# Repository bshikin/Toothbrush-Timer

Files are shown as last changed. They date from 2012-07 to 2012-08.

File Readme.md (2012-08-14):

Toothbrush Timer
=================

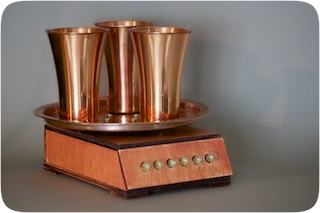
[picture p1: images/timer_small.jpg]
Toothbrush Timer


This is a repository for my toothbrush timer project. It contains schematic and enclosure design and program sources.

You can read how the timer was made in [this Instructable](http://instructables.com/id/Toothbrush-Timer)

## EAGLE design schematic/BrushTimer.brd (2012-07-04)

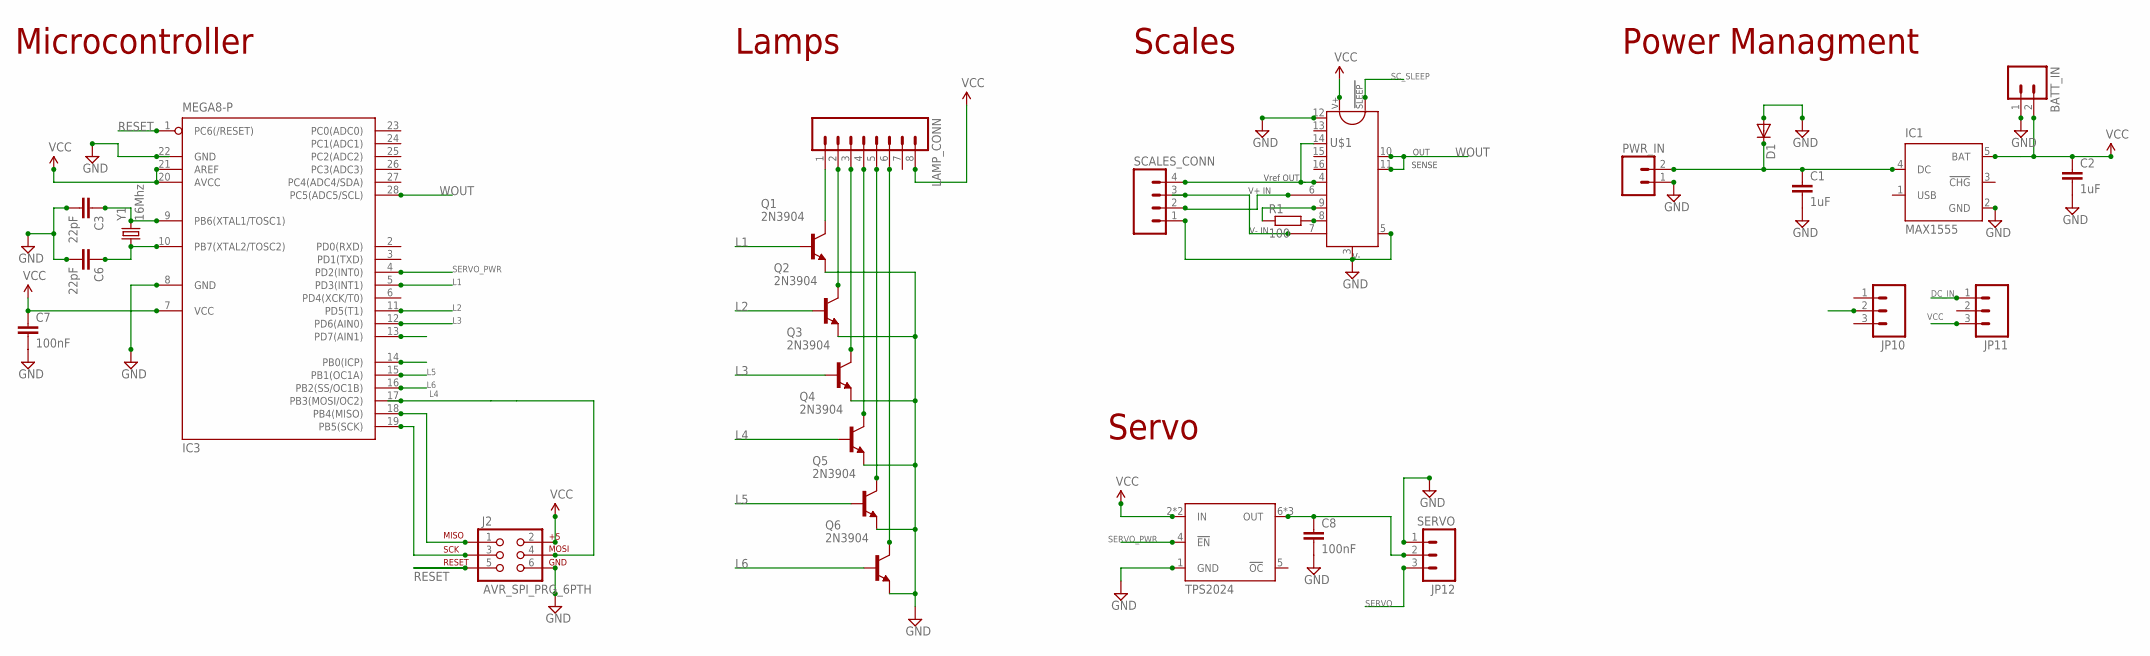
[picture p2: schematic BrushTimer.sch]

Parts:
BATT_IN: M02PTH; 1X02
C1, C2: 1uF; AXIAL-5MM
C3, C6: 22pF; C2.5-2
C7, C8: 100nF; C5B3.5
D1: DIODE-D-2.5; D-2.5
IC1: MAX1555; SOT23-5L
IC3: MEGA8-P; DIL28-3
J2: AVR_SPI_PRG_6PTH; 2X3
JP10, JP11: M03PTH; 1X03
JP12: SERVO; 1X03
LAMP_CONN: M081X08; 1X08
PWR_IN: M02PTH; 1X02
Q1, Q2, Q3, Q4, Q5, Q6: 2N3904; TO92
R1: 100; 0207/5V
SCALES_CONN: M04PTH; 1X04
U$1: INA125; DIL16
U$2: TPS2024; DIL08-OPTO
Y1: 16Mhz; HC49US

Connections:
DC_IN: C1.P$1 (1), D1.C, IC1.4 (DC), JP11.1, PWR_IN.2
GND: BATT_IN.1, C1.P$2 (2), C2.P$2 (2), C3.2, C6.2, C7.2, C8.2, D1.A, IC1.2 (GND), IC3.8 (GND), IC3.22 (GND), J2.6, JP10.2, JP12.1, PWR_IN.1, Q1.3 (E), Q2.3 (E), Q3.3 (E), Q4.3 (E), Q5.3 (E), Q6.3 (E), SCALES_CONN.1, U$1.3, U$1.5, U$1.12, U$2.1 (GND)
L1: IC3.5 (PD3(INT1)), Q1.2 (B)
L1_OUT: LAMP_CONN.1, Q1.1 (C)
L2: IC3.11 (PD5(T1)), Q2.2 (B)
L2_OUT: LAMP_CONN.2, Q2.1 (C)
L3: IC3.12 (PD6(AIN0)), Q3.2 (B)
L3_OUT: LAMP_CONN.3, Q3.1 (C)
L4: IC3.17 (PB3(MOSI/OC2)), J2.4, Q4.2 (B)
L4_OUT: LAMP_CONN.4, Q4.1 (C)
L5: IC3.15 (PB1(OC1A)), Q5.2 (B)
L5_OUT: LAMP_CONN.5, Q5.1 (C)
L6: IC3.16 (PB2(SS/OC1B)), Q6.2 (B)
L6_OUT: LAMP_CONN.6, Q6.1 (C)
MISO: IC3.18 (PB4(MISO)), J2.1
unnamed: SCALES_CONN.2, U$1.6
RESET: IC3.1 (PC6(/RESET)), J2.5
RG1: R1.1, U$1.9
RG2: R1.2, U$1.8
SCK: IC3.19 (PB5(SCK)), J2.3
SC_SLEEP: IC3.13 (PD7(AIN1)), U$1.2
SERVO: IC3.14 (PB0(ICP)), JP12.3
SERVO_PWR: IC3.4 (PD2(INT0)), U$2.4 (!EN)
SERVO_VCC: C8.1, JP12.2, U$2.6 (OUT), U$2.7 (OUT), U$2.8 (OUT)
V-IN: SCALES_CONN.3, U$1.7
VCC: BATT_IN.2, C2.P$1 (1), C7.1, IC1.5 (BAT), IC3.7 (VCC), IC3.20 (AVCC), IC3.21 (AREF), J2.2, JP11.3, LAMP_CONN.8, U$1.1, U$2.2 (IN), U$2.3 (IN)
VREF-OUT: SCALES_CONN.4, U$1.4, U$1.14
WOUT: IC3.28 (PC5(ADC5/SCL)), U$1.10, U$1.11
XTAL9: C3.1, IC3.9 (PB6(XTAL1/TOSC1)), Y1.2
XTAL19: C6.1, IC3.10 (PB7(XTAL2/TOSC2)), Y1.1

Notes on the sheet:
Microcontroller
Lamps
Scales
Power Managment
Servo

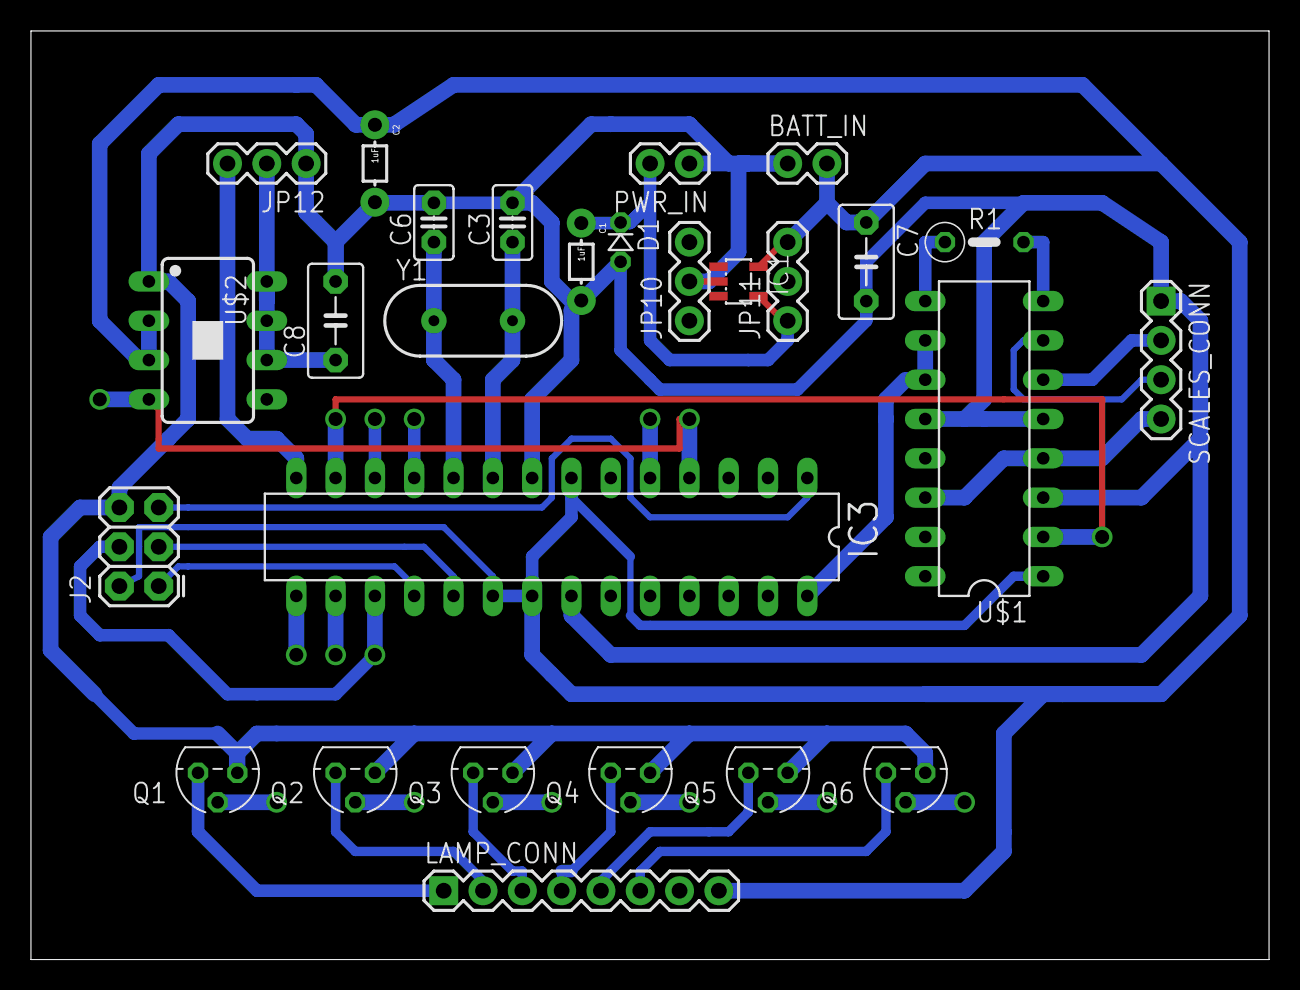
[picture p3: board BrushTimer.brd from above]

Board: 2 copper layers, 80.0 x 60.0 mm, 27 parts (0 on the bottom side), 30 nets.

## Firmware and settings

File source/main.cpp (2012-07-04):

/**
 * Copyright (c) 2012 Basil Shikin, BrushTimer Project
 *
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
 * THE SOFTWARE IS PROVIDED "AS IS", WITHOUT WARRANTY OF ANY KIND, EXPRESS OR
 * IMPLIED, INCLUDING BUT NOT LIMITED TO THE WARRANTIES OF MERCHANTABILITY,
 * FITNESS FOR A PARTICULAR PURPOSE AND NONINFRINGEMENT. IN NO EVENT SHALL THE
 * AUTHORS OR COPYRIGHT HOLDERS BE LIABLE FOR ANY CLAIM, DAMAGES OR OTHER
 * LIABILITY, WHETHER IN AN ACTION OF CONTRACT, TORT OR OTHERWISE, ARISING FROM,
 * OUT OF OR IN CONNECTION WITH THE SOFTWARE OR THE USE OR OTHER DEALINGS IN
 * THE SOFTWARE.
 */

#include "main.h"

extern "C" void __cxa_pure_virtual()
{
  cli();
  for (;;);
}

__extension__ typedef int __guard __attribute__((mode (__DI__)));

void * operator new[](size_t size)
{
    return malloc(size);
}

void operator delete[](void * ptr)
{
    if (ptr)
        free(ptr);
}

int __cxa_guard_acquire(__guard *g) {return !*(char *)(g);}
void __cxa_guard_release (__guard *g) {*(char *)g = 1;}
void __cxa_guard_abort (__guard *) {}


// Pin mappings
#define PIN_L1   9
#define PIN_L2  10
#define PIN_L3  11
#define PIN_L4  3
#define PIN_L5  5
#define PIN_L6  6

#define PIN_SERVO_CONTROL  8
#define PIN_SERVO_POWER    2

#define PIN_SCALES_READING A5
#define PIN_SCALES_POWER   7

// Constants
#define LAMP_COUNT         6
#define DING_COUNT         4
#define WEIGHT_THRESHOLD   0.8
#define ANIMATION_DURATION 120000 // 2 minutes
#define TIME_INCREMENT     100
#define READ_SAMPLES       1000

// Objects
static LampController  s_lampController;
static ServoController s_servoController;
static double          s_lastReading;

// Common numbers
uint32_t dingInterval;
uint32_t lampInterval;
uint32_t dimIncrement;

double readWeight()
{
    // Turn on scales
    digitalWrite(PIN_SCALES_POWER, HIGH);

    // Read average value
    double total = 0;
    for (uint16_t i = 0; i < READ_SAMPLES; i++)
    {
        total += analogRead(PIN_SCALES_READING);
    }

    // Turn off scales
    digitalWrite(PIN_SCALES_POWER, LOW);

    return total / READ_SAMPLES;
}


void setup()
{
    // Setup sleep timer
    su_initialize();

    // Setup common numbers
    dingInterval  = ANIMATION_DURATION/DING_COUNT;
    lampInterval  = ANIMATION_DURATION/LAMP_COUNT;
    dimIncrement  = LAMP_MAX/(lampInterval/TIME_INCREMENT);

    // Initialize servo controller
    s_servoController.initialize( PIN_SERVO_CONTROL, PIN_SERVO_POWER );

    // Initialize lamp controller
    uint8_t lamps[LAMP_COUNT] = {PIN_L1, PIN_L2, PIN_L3, PIN_L4, PIN_L5, PIN_L6};
    s_lampController.initialize( lamps, LAMP_COUNT );
    s_lampController.playInitSequence();

    // Setup weight pin and read baseline weight
    pinMode(PIN_SCALES_POWER, OUTPUT);
    pinMode(PIN_SCALES_READING, INPUT);

    s_lastReading = readWeight();
}

void playAnimation()
{
    s_servoController.ding();
    s_lampController.turnAllOn();

    int32_t  timeRemaining = ANIMATION_DURATION;
    uint8_t  activeLamp = 0;
    uint16_t activeLampBrightness = LAMP_MAX;

    while (timeRemaining > 0)
    {
        if ( timeRemaining < ANIMATION_DURATION )
        {
            if (timeRemaining % dingInterval == 0)
            {
                s_servoController.ding();
            }

            if (timeRemaining % lampInterval == 0 )
            {
                s_lampController.turnOff(activeLamp);
                activeLamp += 1;

                activeLampBrightness = LAMP_MAX;
            }
        }

        // Update current lamp
        s_lampController.setBrightness(activeLamp, activeLampBrightness);
        activeLampBrightness -= dimIncrement;

        timeRemaining -= TIME_INCREMENT;

        delay( TIME_INCREMENT );
    }

    s_servoController.ding();
    s_lampController.turnAllOff();
}

void loop()
{
    double newReading = readWeight();
    if ( s_lastReading - newReading > WEIGHT_THRESHOLD )
    {
        playAnimation();
    }

    s_lastReading = newReading;
}

int main(void)
{
    // Initialize Arduino library
	init();

	// Setup ourselves
	setup();

	while (true)
	{
	    // Do the work
	    loop();

	    // Sleep
	    su_sleep(8);
	}

	return 0;
}

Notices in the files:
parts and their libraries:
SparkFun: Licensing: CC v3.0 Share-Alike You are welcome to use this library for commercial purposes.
